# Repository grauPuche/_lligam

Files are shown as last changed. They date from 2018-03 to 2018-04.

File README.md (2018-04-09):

# v02

The point of this version is to take the already working device and make it wireless. To do so I'm using the well known ESP8266. this is going to take the analog data from the joystick and send it to a node server. This is the main objective of this version.

The plan for the following is to have a client side for the mentioned information. And to do the first steps towards the creation of the final iteration of the controller and make the custom board I need for it.

---

## HARDWARE

**As of april 8th**, the webSocket enabled joystick is completely functional, *.ino* is sending data properly and server is displaying it at [lligam.grrau.co](http://lligam.grrrau.co). There are still some things to be adjusted and others to be added, but the core functionality is working exactly as intended. At this point the next step is building the multiplexer to have both axis of the joystick read by one pin.





---

**As of march 8th**, *.ino* code working, X & Y values are not showing properly. either a hardware.wiring problem, or a code/pinout issue. the issue is that I was dumb enough to switch the meaning of analog with PWD. and feather only has one analogRead Pin. Wiring has to be UPDATED.





---

## what I'm using

As mentioned; a [HUZZAH feather](https://www.adafruit.com/product/2821)  with ESP8266 from Adafruit. to run the basic operations needed before designing the PCB. Where I'll be using [this](https://www.adafruit.com/product/2491).

To set everything up, I've been following the [tutorials given by Adafruit](https://learn.adafruit.com/adafruit-feather-huzzah-esp8266)

---

## SOFTWARE

**As of march 8th** the third version of the software is up and running. This v. is the first step to completion. At this point there are two servers running through *grrrau.co*, one is a **webSocket** server (called *mitjons*) and the other on is a simple **express** server (called *lligam*). *Mitjons* is getting the data from the *esp8266* and sending it to *lligam* which interprets and displays it. The next step in software is to instead of displaying this information is using it to read the patterns and use it to link it to the required movements from the joystick.

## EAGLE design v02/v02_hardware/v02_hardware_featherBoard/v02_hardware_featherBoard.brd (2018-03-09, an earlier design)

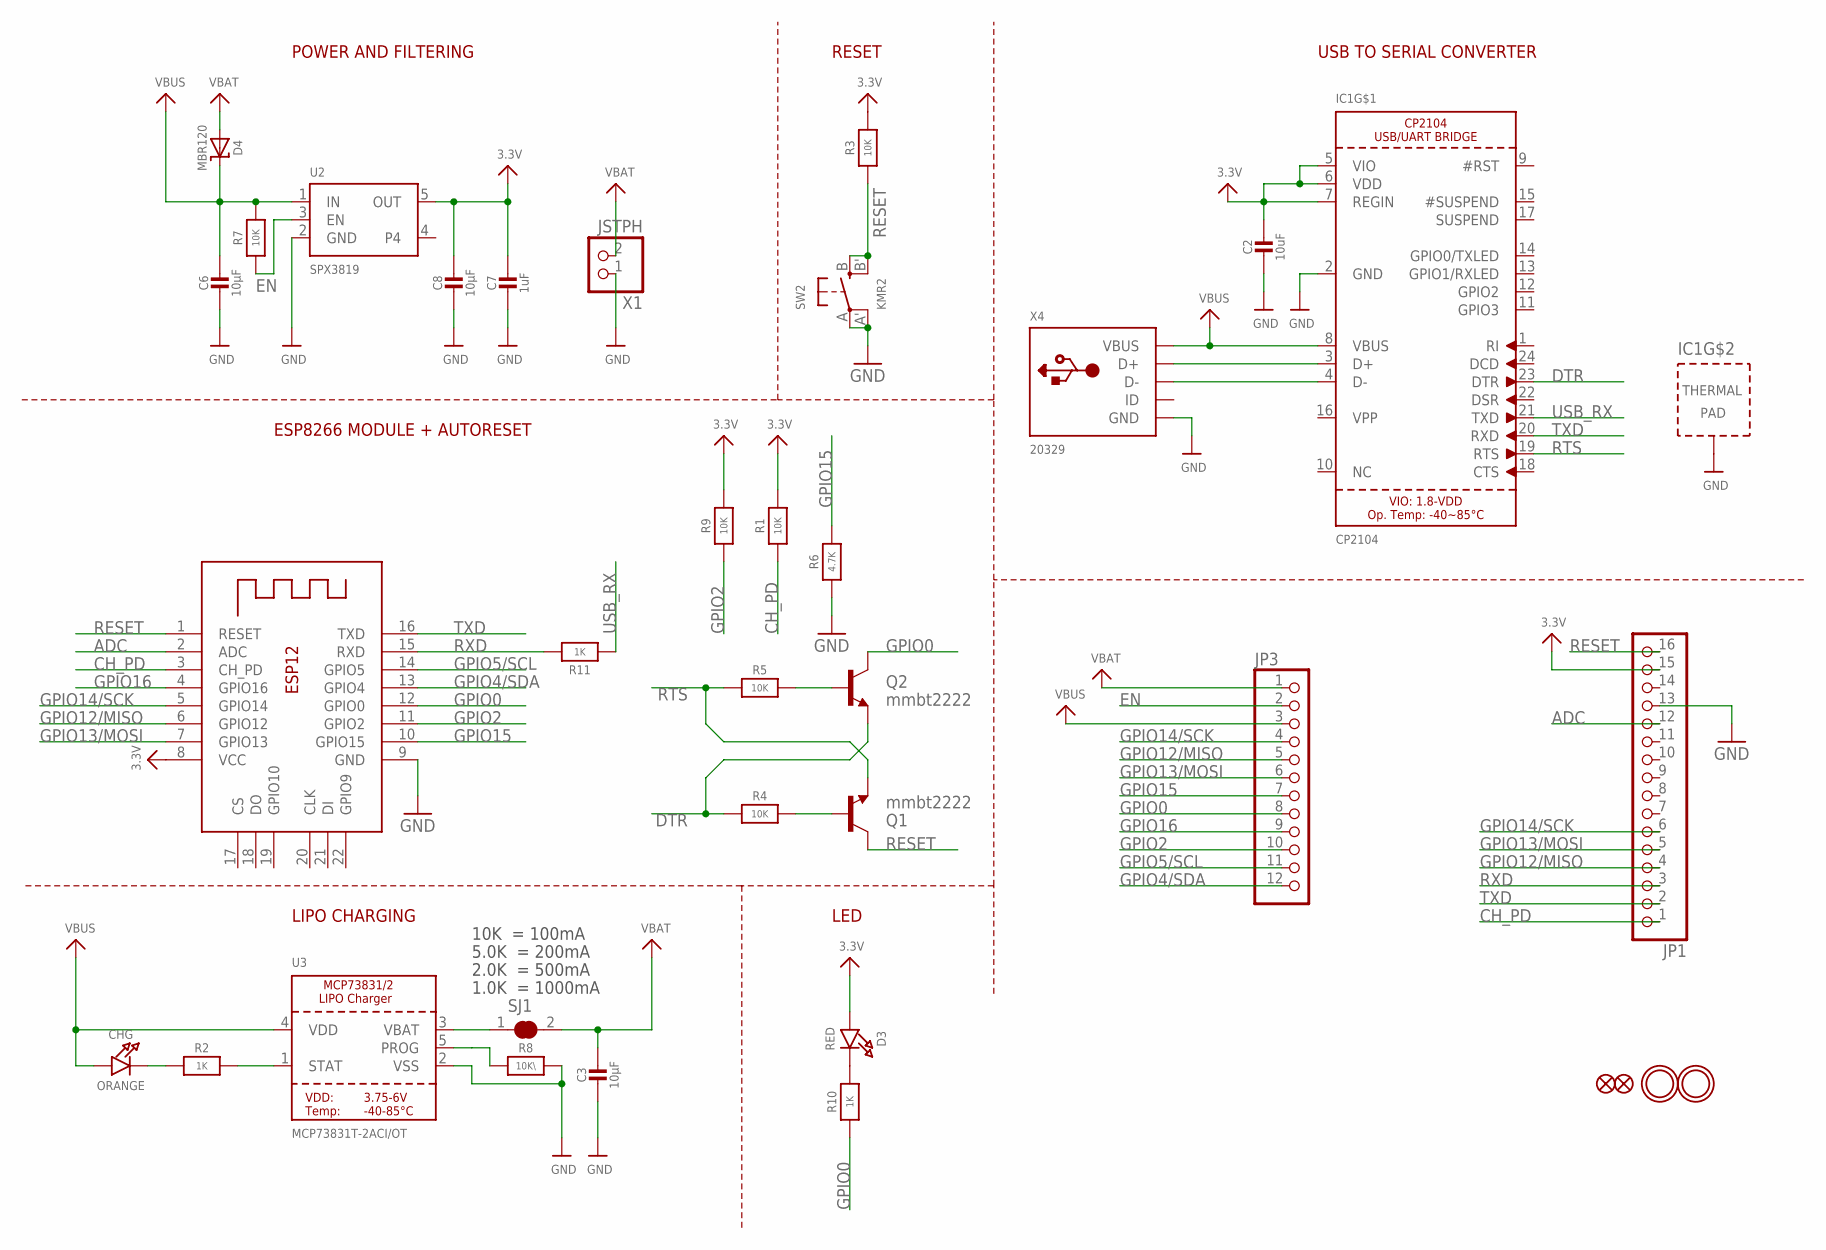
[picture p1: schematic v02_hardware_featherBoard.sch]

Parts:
C2: 10uF; 0805-NO
C3, C6, C8: 10µF; 0805-NO
C7: 1uF; 0603-NO
CHG: ORANGE; CHIPLED_0805_NOOUTLINE
D3: RED; CHIPLED_0805_NOOUTLINE
D4: MBR120; SOD-123
IC1: CP2104; QFN24_4MM_SMSC
JP1: HEADER-1X16ROUND; 1X16_ROUND
JP3: HEADER-1X12; 1X12_ROUND
Q1, Q2: mmbt2222; SOT23-3
R1, R3, R4, R7, R9: 10K; 0603-NO
R2, R10: 1K; 0603-NO
R5: 10K; _0603MP
R6: 4.7K; 0603-NO
R8: 10K\; 0603-NO
R11: 1K; _0603MP
SJ1: SOLDERJUMPER_CLOSED; SOLDERJUMPER_CLOSEDWIRE
SW2: KMR2; BTN_KMR2_4.6X2.8
U2: SPX3819; SOT23-5
U3: MCP73831T-2ACI/OT; SOT23-5
U$31, U$32: MOUNTINGHOLE2.5; MOUNTINGHOLE_2.5_PLATED
U$34, U$35: FIDUCIAL""; FIDUCIAL_1MM
X1: JSTPH; JSTPH2
X2: ESP-12; ESP-12E
X4: 20329; 4UCONN_20329_V2

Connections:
3.3V: C2.1, C7.1, C8.1, D3.A, IC1.5 (VIO), IC1.6 (VDD), IC1.7 (REGIN), JP1.15, R1.2, R3.2, R9.2, U2.5 (OUT), X2.8 (VCC)
ADC: JP1.12, X2.2 (ADC)
CH_PD: JP1.1, R1.1, X2.3 (CH_PD)
DTR: IC1.23 (DTR), Q2.2 (E), R4.1
EN: JP3.2, R7.1, U2.3 (EN)
GND: C2.2, C3.2, C6.2, C7.2, C8.2, IC1.2 (GND), IC1.THERM (TP), JP1.13, R6.1, R8.2, SW2.A, SW2.A' (P1), U2.2 (GND), U3.2 (VSS), X1.1, X2.9 (GND), X4.BASE@1 (GND), X4.BASE@2 (GND), X4.GND, X4.SPRT@1 (GND), X4.SPRT@2 (GND), X4.SPRT@3 (GND), X4.SPRT@4 (GND)
GPIO0: JP3.8, Q2.3 (C), R10.1, X2.12 (GPIO0)
GPIO2: JP3.10, R9.1, X2.11 (GPIO2)
GPIO4/SDA: JP3.12, X2.13 (GPIO4)
GPIO5/SCL: JP3.11, X2.14 (GPIO5)
GPIO12/MISO: JP1.4, JP3.5, X2.6 (GPIO12)
GPIO13/MOSI: JP1.5, JP3.6, X2.7 (GPIO13)
GPIO14/SCK: JP1.6, JP3.4, X2.5 (GPIO14)
GPIO15: JP3.7, R6.2, X2.10 (GPIO15)
GPIO16: JP3.9, X2.4 (GPIO16)
unnamed: CHG.C, R2.1
unnamed: IC1.3 (D+), X4.D+
unnamed: R2.2, U3.1 (STAT)
unnamed: R8.1, U3.5 (PROG)
unnamed: D3.C, R10.2
unnamed: IC1.4 (D-), X4.D-
unnamed: SJ1.1, U3.3 (VBAT)
unnamed: Q1.1 (B), R4.2
unnamed: Q2.1 (B), R5.2
RESET: JP1.16, Q1.3 (C), R3.1, SW2.B (S), SW2.B' (S1), X2.1 (RESET)
RTS: IC1.19 (RTS), Q1.2 (E), R5.1
RXD: JP1.3, R11.2, X2.15 (RXD)
TXD: IC1.20 (RXD), JP1.2, X2.16 (TXD)
USB_RX: IC1.21 (TXD), R11.1
VBAT: C3.1, D4.A, JP3.1, SJ1.2, X1.2
VBUS: C6.1, CHG.A, D4.C, IC1.8 (VBUS), JP3.3, R7.2, U2.1 (IN), U3.4 (VDD), X4.VBUS

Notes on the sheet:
POWER AND FILTERING
RESET
10K = 100mA
5.0K = 200mA
2.0K = 500mA
1.0K = 1000mA
USB TO SERIAL CONVERTER
LIPO CHARGING
LED
ESP8266 MODULE + AUTORESET

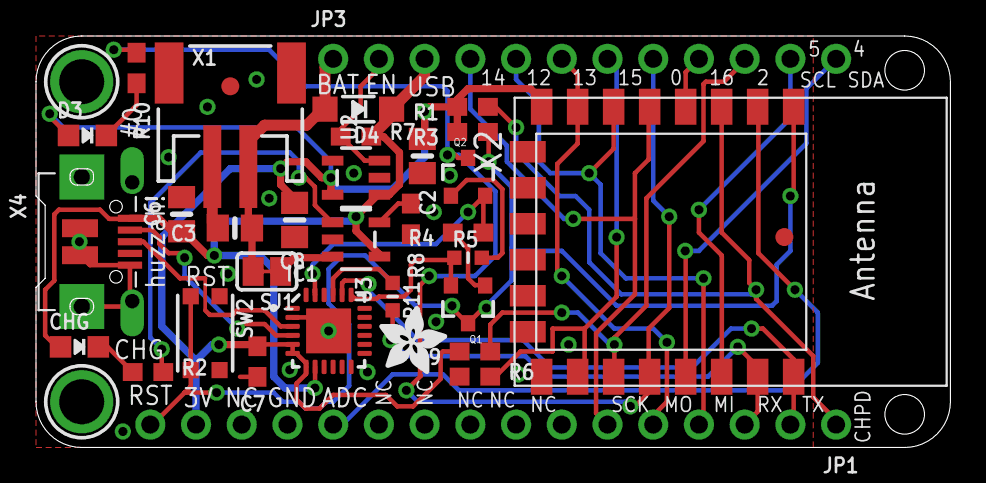
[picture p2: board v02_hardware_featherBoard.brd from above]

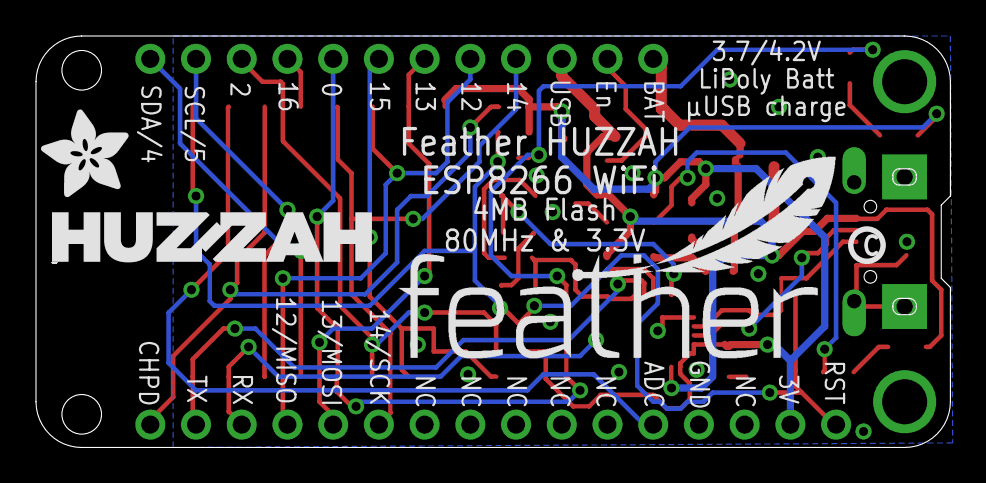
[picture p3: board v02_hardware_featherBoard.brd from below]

Board: 2 copper layers, 50.8 x 22.9 mm, 40 parts (4 on the bottom side), 31 nets.

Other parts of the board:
U$7: ADAFRUIT_5MM
U$9: FEATHERLOGO
U$13: PCBFEAT-REV-040
U$15: ADAFRUIT_3.5MM
U$23: HUZZAHLOGO

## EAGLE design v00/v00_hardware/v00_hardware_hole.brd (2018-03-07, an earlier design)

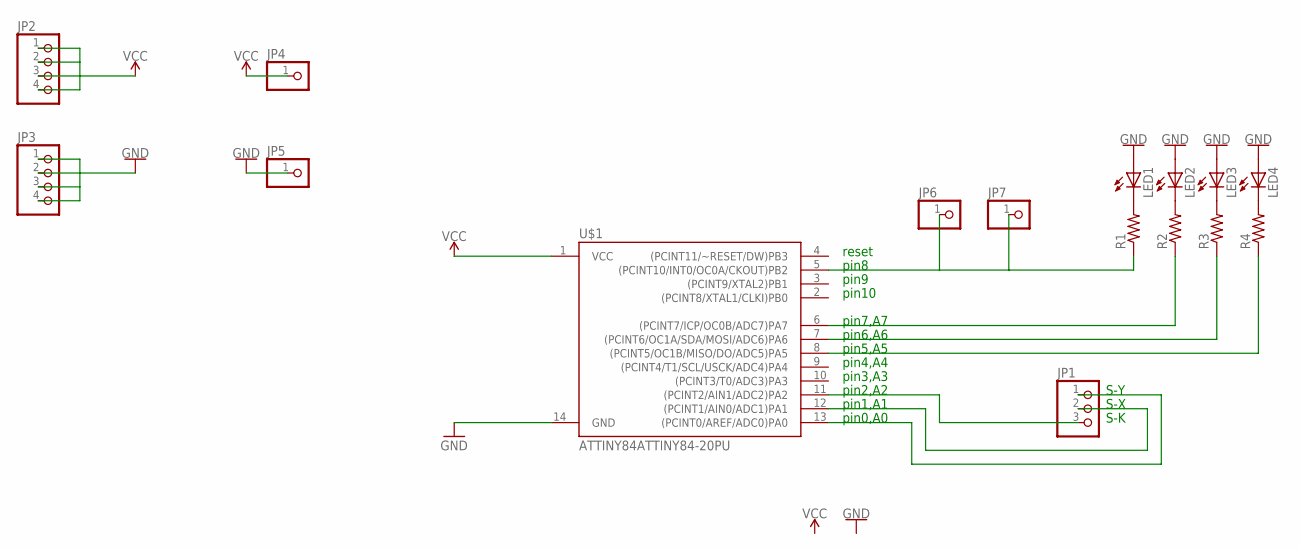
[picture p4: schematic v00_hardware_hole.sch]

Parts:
JP1: PINHD-1X3; 1X03
JP2, JP3: PINHD-1X4; 1X04
JP4, JP5, JP6, JP7: PINHD-1X1; 1X01
LED1, LED2, LED3, LED4: LED5MM
R1, R2, R3, R4: R-US_0204/7; 0204/7
U$1: ATTINY84ATTINY84-20PU; DIP14

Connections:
GND: JP3.1, JP3.2, JP3.3, JP3.4, JP5.1, LED1.A, LED2.A, LED3.A, LED4.A, U$1.14 (GND)
unnamed: LED1.K (C), R1.2
unnamed: LED2.K (C), R2.2
unnamed: LED3.K (C), R3.2
unnamed: LED4.K (C), R4.2
unnamed: JP1.1, U$1.13 ((PCINT0/AREF/ADC0)PA0)
unnamed: JP1.2, U$1.12 ((PCINT1/AIN0/ADC1)PA1)
unnamed: JP6.1, JP7.1, R1.1, U$1.5 ((PCINT10/INT0/OC0A/CKOUT)PB2)
unnamed: R2.1, U$1.6 ((PCINT7/ICP/OC0B/ADC7)PA7)
unnamed: R3.1, U$1.7 ((PCINT6/OC1A/SDA/MOSI/ADC6)PA6)
unnamed: R4.1, U$1.8 ((PCINT5/OC1B/MISO/DO/ADC5)PA5)
unnamed: JP1.3, U$1.11 ((PCINT2/AIN1/ADC2)PA2)
VCC: JP2.1, JP2.2, JP2.3, JP2.4, JP4.1, U$1.1 (VCC)

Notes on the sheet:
S-Y
S-X
S-K
pin10
pin9
pin8
pin7,A7
pin6,A6
pin5,A5
pin4,A4
pin3,A3
pin2,A2
pin1,A1
pin0,A0
reset

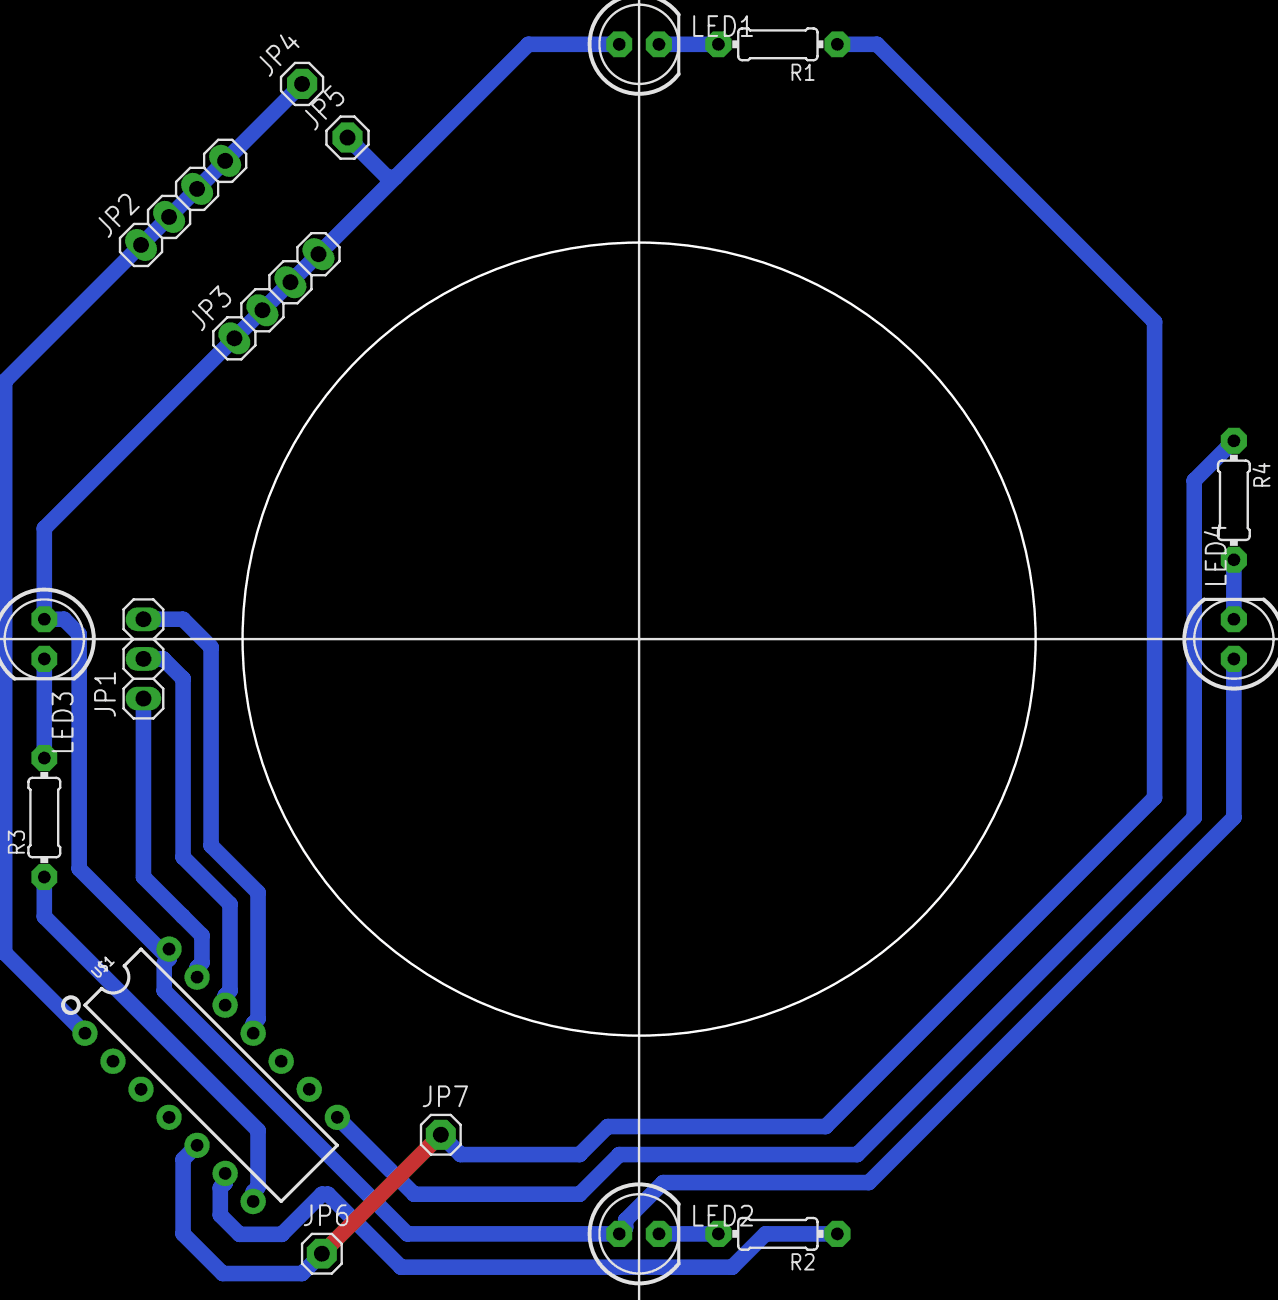
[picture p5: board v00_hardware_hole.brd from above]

Board: 2 copper layers, 16 parts (0 on the bottom side), 13 nets.

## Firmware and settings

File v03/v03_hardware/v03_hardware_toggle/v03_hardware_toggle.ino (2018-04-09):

#include <Arduino.h>

#include <ESP8266WiFi.h>
#include <ESP8266WiFiMulti.h>

#include <WebSocketsClient.h>

#include <Hash.h>

ESP8266WiFiMulti WiFiMulti;
WebSocketsClient webSocket;

#define USE_SERIAL Serial

//boolean isConnected = false;

int sendState = LOW;         // the current state of the output pin
int buttonState;             // the current reading from the input pin
int lastButtonState = LOW;   // the previous reading from the input pin

// the following variables are unsigned long's because the time, measured in miliseconds,
// will quickly become a bigger number than can be stored in an int.
unsigned long lastDebounceTime = 0;  // the last time the output pin was toggled
unsigned long debounceDelay = 50;    // the debounce time; increase if the output flickers


void webSocketEvent(WStype_t type, uint8_t * payload, size_t length) {

  switch (type) {
    case WStype_DISCONNECTED:
      USE_SERIAL.printf("[WSc] Disconnected!\n");
      break;
    case WStype_CONNECTED: {
        USE_SERIAL.printf("[WSc] Connected to url: %s\n", payload);

        // send message to server when Connected
        webSocket.sendTXT("~CTRL~"); // showing undefined on node console
        //        isConnected = true;

      }
      break;
    case WStype_TEXT:
      USE_SERIAL.printf("[WSc] get text: %s\n", payload);

      // send message to server
      // webSocket.sendTXT("message here");
      break;
    case WStype_BIN:
      USE_SERIAL.printf("[WSc] get binary length: %u\n", length);
      hexdump(payload, length);

      // send data to server
      // webSocket.sendBIN(payload, length);
      break;
  }

}

const int yPin = A0;
const int xPin = 5;
const int kPin = 4;

int yValue = 0;
int xValue = 0;
int kValue = 0;

const int sendPin = 13;
const int ledPin = 12;      // the number of the LED pin



void setup() {

  pinMode(sendPin, INPUT);
  pinMode(ledPin, OUTPUT);
  pinMode(kPin, INPUT);
  pinMode(yPin, INPUT);
  pinMode(xPin, INPUT);

  digitalWrite(ledPin, sendState);

  // USE_SERIAL.begin(921600);
  USE_SERIAL.begin(115200);

  //Serial.setDebugOutput(true);
  USE_SERIAL.setDebugOutput(true);

  USE_SERIAL.println();
  USE_SERIAL.println();
  USE_SERIAL.println();

  for (uint8_t t = 4; t > 0; t--) {
    USE_SERIAL.printf("[SETUP] BOOT WAIT %d...\n", t);
    USE_SERIAL.flush();
    delay(1000);
  }

  WiFiMulti.addAP("itpsandbox", "NYU+s0a!+P?");
  WiFiMulti.addAP("lacueva", "monsterGr4u");

  //WiFi.disconnect();
  while (WiFiMulti.run() != WL_CONNECTED) {
    delay(100);
  }

  // server address, port and URL
  webSocket.begin("mitjons.grrrau.co", 80, "/");

  // event handler
  //  while (!isConnected) {


  webSocket.onEvent(webSocketEvent);

  // use HTTP Basic Authorization this is optional remove if not needed
  //webSocket.setAuthorization("user", "Password");

  // try ever 5000 again if connection has failed
  webSocket.setReconnectInterval(5000);

  //  }
}

void loop() {



  int sendReading = digitalRead(sendPin);
  if (sendReading != lastButtonState) {
    // reset the debouncing timer
    lastDebounceTime = millis();
  }

  if ((millis() - lastDebounceTime) > debounceDelay) {
    // whatever the reading is at, it's been there for longer
    // than the debounce delay, so take it as the actual current state:

    // if the button state has changed:
    if (sendReading != buttonState) {
      buttonState = sendReading;

      // only toggle the LED if the new button state is HIGH
      if (buttonState == HIGH) {
        sendState = !sendState;
      }
    }
  }

//  Serial.println(sendState);

  lastButtonState = sendReading;

  yValue = analogRead(yPin);
  kValue = digitalRead(kPin);

  if (sendState == 1) {
    String coma = ",";
    webSocket.sendTXT(yValue + coma + kValue);
    // delay(200);
    
  }

  digitalWrite(ledPin, sendState);

  webSocket.loop();
  delay(50);
}

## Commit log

2018-03-07 hardware changes
    [v00_hardware_hole.brd, v00_hardware_hole.sch]
2018-03-09 readme added + eagle Files for the feather
    [v02_hardware_featherBoard.brd, v02_hardware_featherBoard.sch]
2018-03-26 v02 software + updated general hardware
    [v00_hardware.sch, v00_hardware_hole.sch]
2018-04-06 [v02] hardware - v02 complete
    [v03_hardware_0.sch]

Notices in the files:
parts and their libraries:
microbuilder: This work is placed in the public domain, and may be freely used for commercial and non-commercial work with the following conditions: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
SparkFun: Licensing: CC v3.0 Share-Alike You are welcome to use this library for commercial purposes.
